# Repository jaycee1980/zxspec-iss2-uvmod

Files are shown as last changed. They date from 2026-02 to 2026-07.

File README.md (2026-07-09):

# ZX Spectrum Issue Two UV Mod

This is a a small modification board to add the autobias circuit for the U and V video signals, present in Issue 3 and later Spectrums, to an Issue 2 Spectrum.

It eliminates the annoying VR1 and VR2 trimmer potentiometers, and thus the need to "tune" the signal for a correct colour picture. This helps enormously as these settings often drift with temperature, and can drift with aging of the ULA. Some ULA's become impossible to "tune" as they age.

Additional thanks to Jim Smith of [Happy Little Diodes](https://www.youtube.com/c/HappyLittleDiodes) as he helped me develop this board. The original inspiration came from [one of his videos](https://www.youtube.com/watch?v=m4PCPcdD4Uw) and after watching it I wondered how do-able it was to adapt an Issue 2 board to use the autobias circuit from the Issue 3 and later, and whether it would help with the "untunaeable" ULA he had in the video.

I proposed prototyping a modification using a circuit on Veroboard, and he tested this out [here](https://www.youtube.com/watch?v=yTBOfa4Heks), including an early revision of the modification board. We revised it a bit so it was neater and easier to fit, and this is the result :)

In [this](https://www.youtube.com/watch?v=-wrouM9OnbY) video Jim shows the final version of the mod board fitted, including the ordering process with [PCBWay](https://www.pcbway.com)

# How to install it

* Solder some wires to the GND, 5V and Y terminals of the mod board PCB
* Remove R38, R39, R40, R41, R56, R63, C52, C53, VR1, VR2 from the Spectrum PCB
* Fit a 470 Ohm 1/4 watt resistor between the right hand terminal of R41, and a +5V supply. Refer to the picture below to see the recommended fitting.

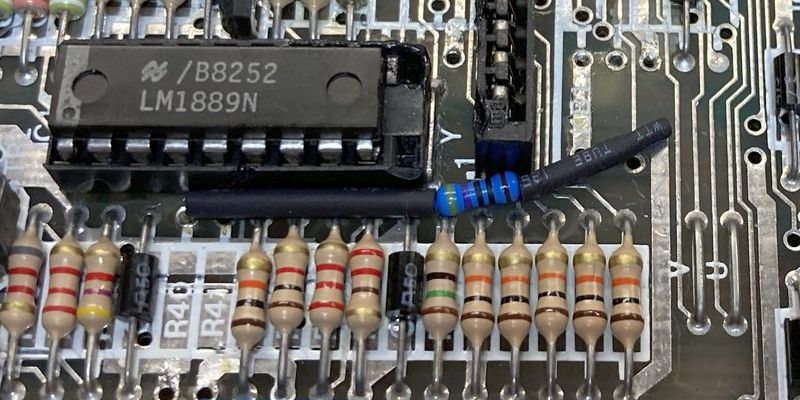
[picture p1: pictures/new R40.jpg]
Placement of the 470 ohm resistor


* Fit some 2.54mm pitch header pins to the PCB, in the right hand holes where C52, R56, C53 and R63 were fitted (see picture)

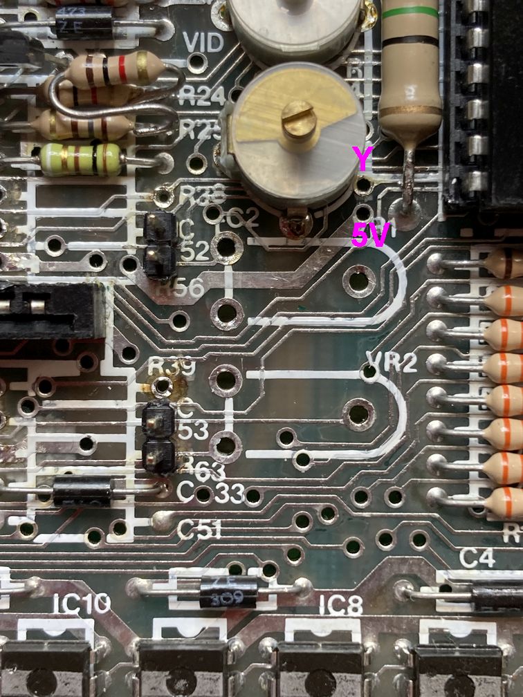
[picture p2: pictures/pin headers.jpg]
Placement of the pin headers and where to get 5V and Y


* Fit the mod board so the header pins go through the appropriate holes on the mod board, and solder in place.
* Solder the wires to the Spectrum PCB to make the appropriate connections. GND can be found on the R63's left hand pad. 5V can be found on the bottom leg of the large 15 ohm resistor next to the ULA, and Y can be found on the Y link underneath the LM1889. Alternatively see the picture above for holes which carry the appropriate signals. You will need to remove some soldermask on the underside of the board if you use those.

The final result should look much like this:
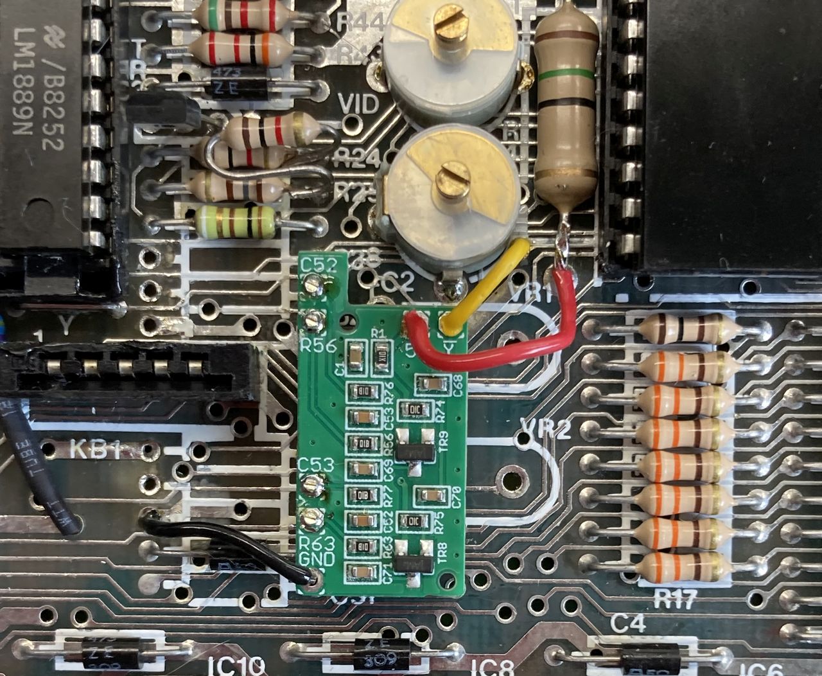
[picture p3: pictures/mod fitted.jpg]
Fitted mod PCB


# What's included here

Here you will find the EAGLE project files, a schematic, Gerber files, and BOM+CPL files for use with [JLCPCB](https://jlcpcb.com)'s self assembly service.

# Getting PCBs
Jim has a [PCBWay Shared Project](https://www.pcbway.com/project/shareproject/ZX_Spectrum_Issue_Two_UV_Mod_ba1552a4.html)

You can also have them made by [JLCPCB](https://jlcpcb.com) using the BOM, CPL and Gerber files provided

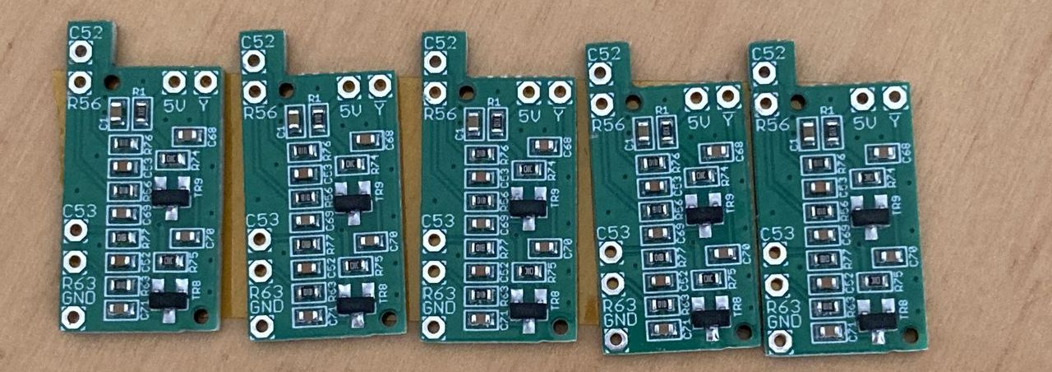
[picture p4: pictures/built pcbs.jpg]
New mod PCBs


# License

This project is licensed under the [Creative Commons Attribution-NonCommercial-ShareAlike (CC BY-NC-SA)](https://creativecommons.org/licenses/by-nc-sa/4.0/) license.

I am not responsible for any Spectrums damaged due to fitting this mod!

If you want to sell prebuilt PCB's on your retro store, please contact me at github@dark-matter.me.uk. I will normally grant this provided they are sold for reasonable cost.

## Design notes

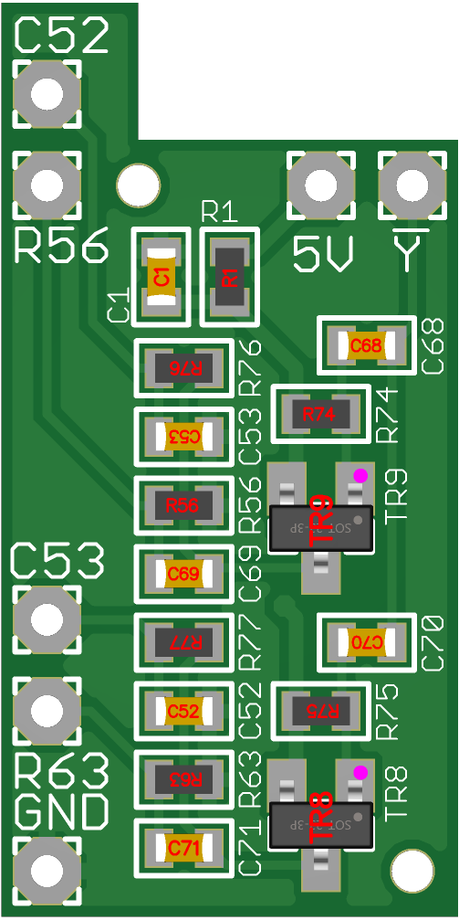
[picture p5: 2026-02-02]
pictures/PCB.png

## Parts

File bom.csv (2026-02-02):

Comment | Designator | Footprint | LCSC Part #
1K | R56 R63 R76 R77 | 0603 | C21190
1u | C1 | 0603 | C15849
10 | R1 | 0603 | C22859
10K | R74 R75 | 0603 | C25804
100n | C68 C69 C70 C71 | 0603 | C14663
150p | C52 C53 | 0603 | C1594
MMBT3904 | TR8 TR9 | SOT23 | C20526

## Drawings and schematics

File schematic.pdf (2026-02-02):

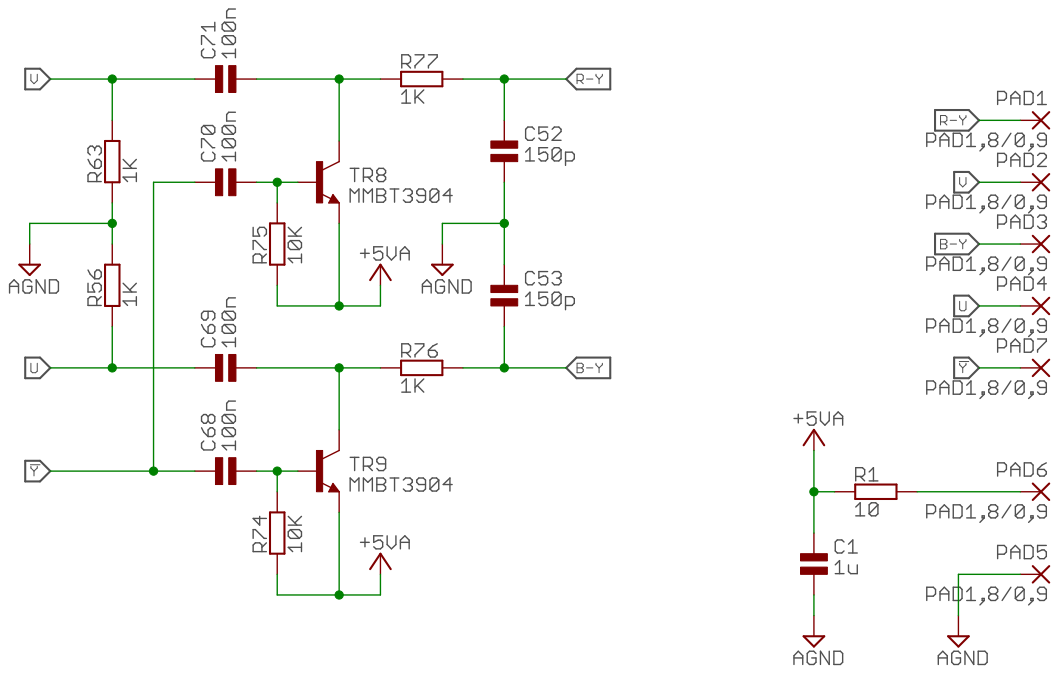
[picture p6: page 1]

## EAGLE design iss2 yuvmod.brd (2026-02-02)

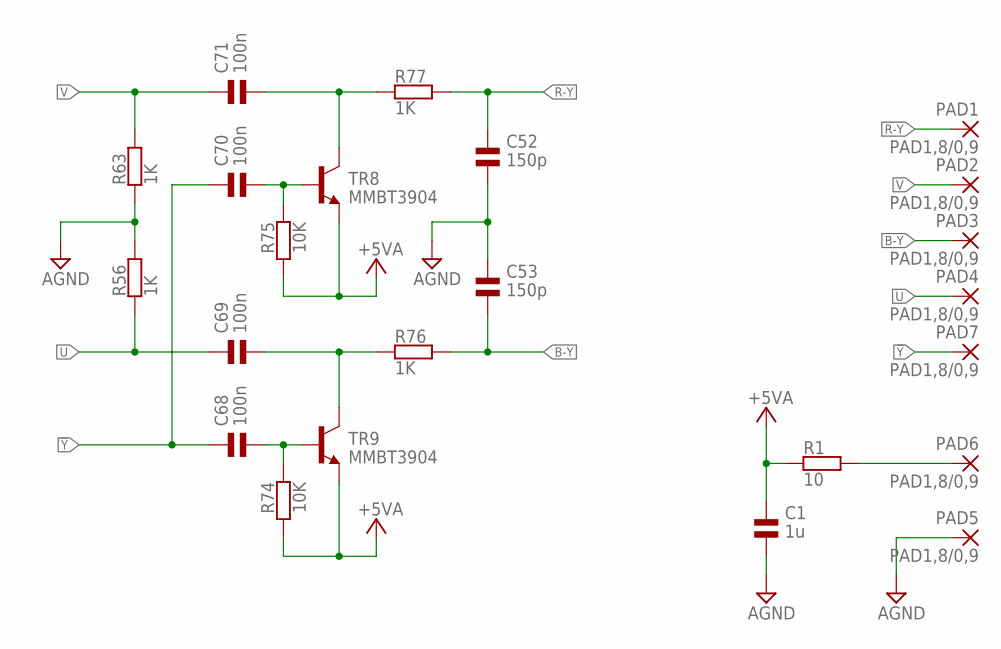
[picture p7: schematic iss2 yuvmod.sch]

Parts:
C1: 1u; 0603; LCSC_PART C15849
C52, C53: 150p; 0603; LCSC_PART C1594
C68, C69, C70, C71: 100n; 0603; LCSC_PART C14663
PAD1, PAD2, PAD3, PAD4, PAD5, PAD6, PAD7: PAD1,8/0,9; 1,8/0,9
R1: 10; 0603; LCSC_PART C22859
R56, R63, R76, R77: 1K; 0603; LCSC_PART C21190
R74, R75: 10K; 0603; LCSC_PART C25804
TR8, TR9: MMBT3904; SOT23; LCSC_PART C20526

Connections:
!Y: C68.1, C70.1, PAD7.1
+5VA: C1.1, R1.1, R74.2, R75.2, TR8.2 (E), TR9.2 (E)
AGND: C1.2, C52.2, C53.1, PAD5.1, R56.2, R63.1
B-Y: C53.2, PAD3.1, R76.2
unnamed: PAD6.1, R1.2
unnamed: C68.2, R74.1, TR9.1 (B)
unnamed: C70.2, R75.1, TR8.1 (B)
unnamed: C71.2, R77.1, TR8.3 (C)
unnamed: C69.2, R76.1, TR9.3 (C)
R-Y: C52.1, PAD1.1, R77.2
U: C69.1, PAD4.1, R56.1
V: C71.1, PAD2.1, R63.2

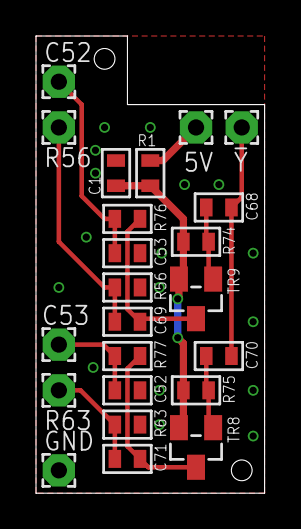
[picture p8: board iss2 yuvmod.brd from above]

Board: 2 copper layers, 12.7 x 25.4 mm, 23 parts (0 on the bottom side), 12 nets.

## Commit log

2026-02-02 Add content
    [bom.csv, iss2 yuvmod.brd, iss2 yuvmod.sch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]
2026-02-02 Added annotation of where to find the 5V and Y signal holes in the PCB
2026-02-02 Cropped picture of built pcb's
2026-06-17 Correct picture showing where 5V and Y are - they were reversed!!!
